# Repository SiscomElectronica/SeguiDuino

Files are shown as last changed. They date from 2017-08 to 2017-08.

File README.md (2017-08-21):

# SeguiDuino

Shield seguidor de lineas para el Arduino UNO

## Descripcion

El proyecto consta de 3 archivos importantes:

*SiscomSeguidor_1.sch: Diagrama electrico del proyecto

*SiscomSeguidor_1.brd: Archivo del diseño del circuito impreso

*SiscomSeguidor_Componentes.pdf: Archivo PDF de los componentes del circuito

*SiscomSeguidor_Pistas.pdf: Archivo PDF con el diseño de pistas

## Consideraciones

Muchos componentes fueron modificados desde su libreria, asi que puede 
marcar algunos errores con respecto a su descarga y posterior modifcacion.

Con respecto a su fabricacion al no tener archivos (.gbr) gerber es 
necesario contactar al fabricante y proporcionarle el archivo 
Siscom_SEGUIDOR.brd para su posterior manufacturacion.

Diseñado por: [Josue Echeverria](https://www.facebook.com/josue.echeverria.583)

Team SISCOM.

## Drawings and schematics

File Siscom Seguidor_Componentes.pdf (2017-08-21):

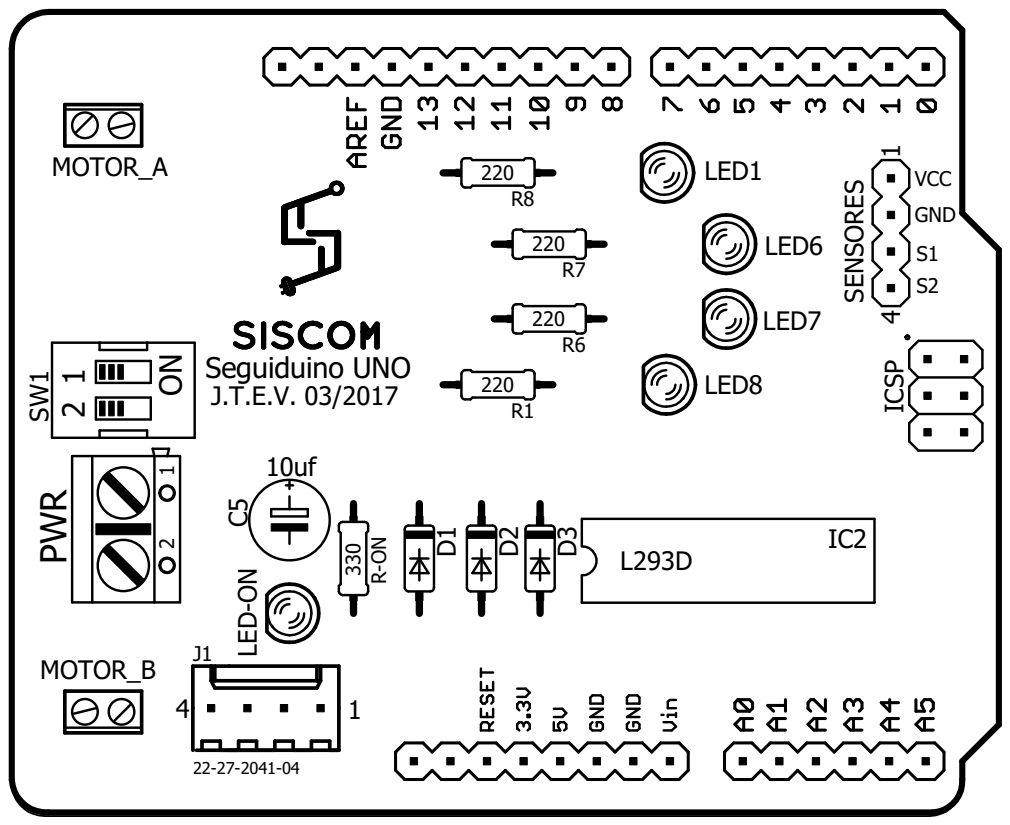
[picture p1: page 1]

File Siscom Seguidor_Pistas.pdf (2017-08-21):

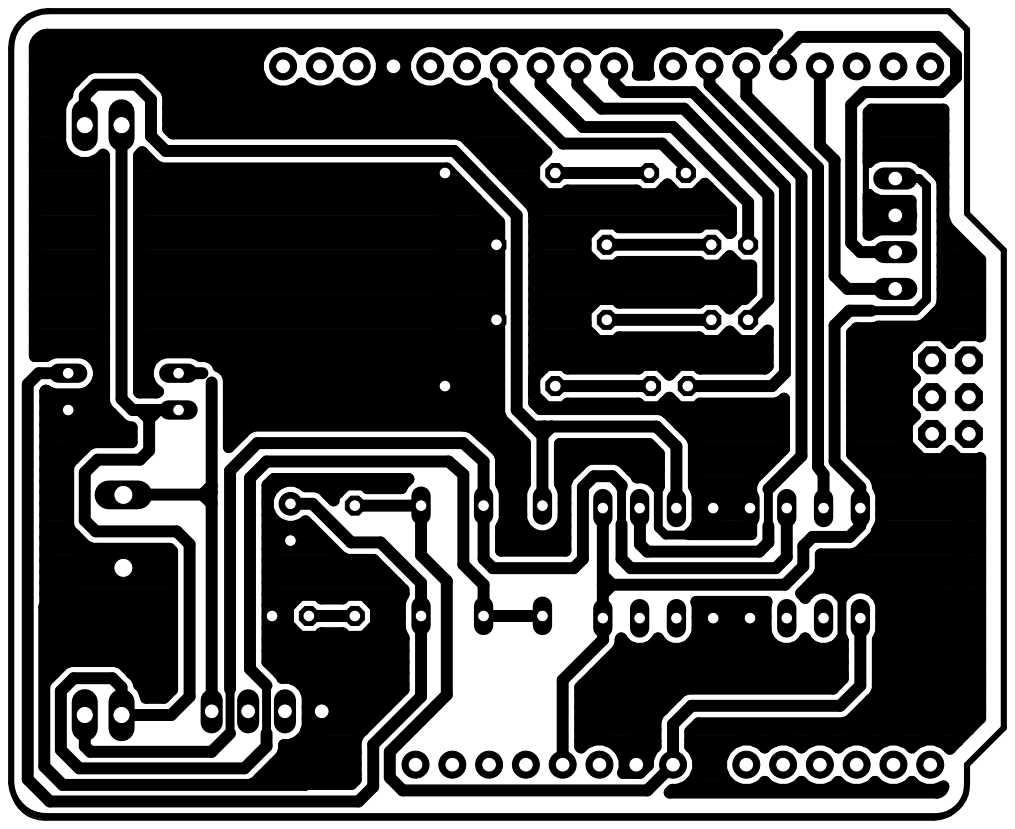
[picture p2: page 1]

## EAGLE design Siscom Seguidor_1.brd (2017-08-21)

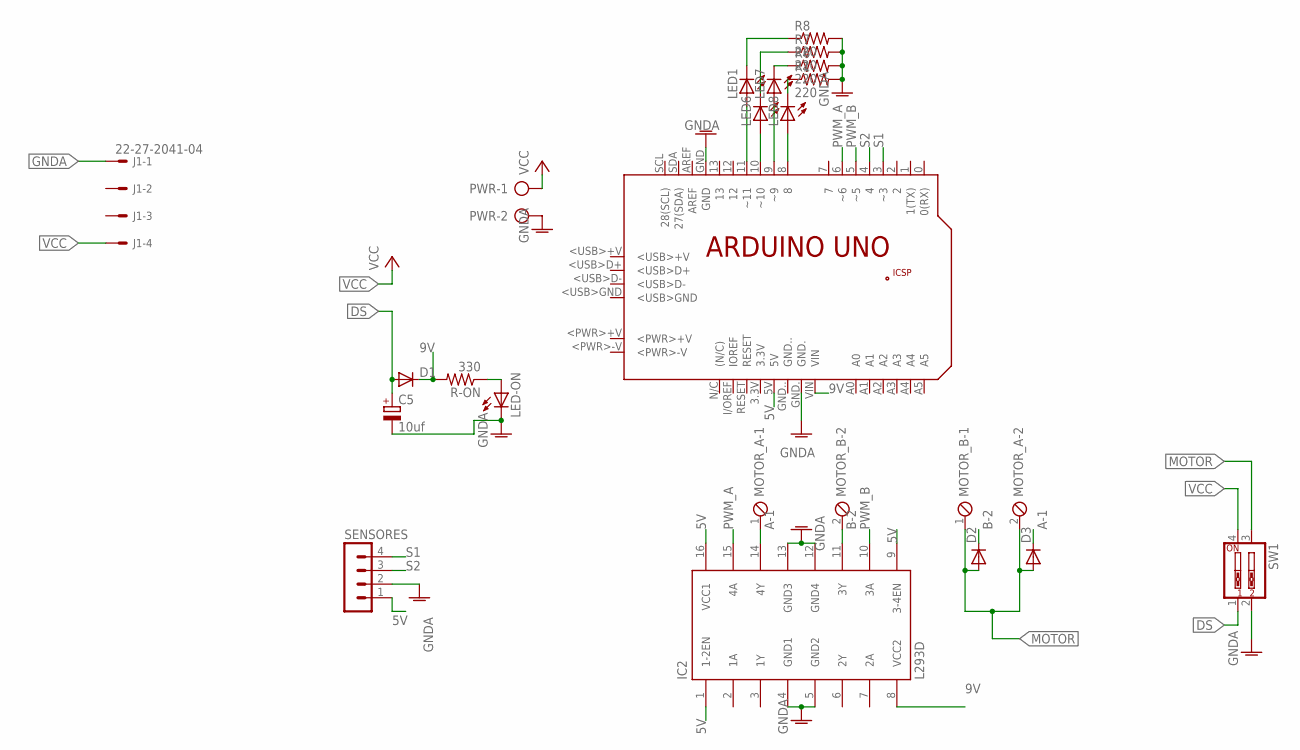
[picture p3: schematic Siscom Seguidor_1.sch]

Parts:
C5: 10uf; E2,5-6E
D1, D2, D3: 1N4148DO35-7; DO35-7
IC2: L293D; DIL16
J1: 22-27-2041-04; 6410-04
LED1, LED6, LED7, LED8: LED3MM
LED-ON: LED3MM
MOTOR_A: MPT2; 2POL254
MOTOR_B: MPT2; 2POL254
PCB2: ARDUINO_UNO
PWR: AK500/2
R1, R6, R7, R8: 220; 0204/7
R-ON: 330; 0204/7
SENSORES: MA04-1
SW1: SW_DIP-2; EDG-02

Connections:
5V: IC2.1 (1-2EN), IC2.9 (3-4EN), IC2.16 (VCC1), PCB2.5V, SENSORES.1
9V: D1.C, IC2.8 (VCC2), PCB2.VIN, R-ON.2
A-1: D3.C, IC2.14 (4Y), MOTOR_A.1
B-2: D2.C, IC2.11 (3Y), MOTOR_B.2
DS: C5.+, D1.A, SW1.1
GNDA: C5.-, IC2.4 (GND1), IC2.5 (GND2), IC2.12 (GND4), IC2.13 (GND3), J1.1, LED-ON.K (C), PCB2.GND, PCB2.GND., PWR.2, R1.2, R6.2, R7.2, R8.2, SENSORES.2, SW1.2
MOTOR: D2.A, D3.A, MOTOR_A.2, MOTOR_B.1, SW1.3
unnamed: LED-ON.A, R-ON.1
unnamed: LED8.K (C), R1.1
unnamed: LED7.K (C), R6.1
unnamed: LED6.K (C), R7.1
unnamed: LED1.K (C), R8.1
unnamed: LED7.A, PCB2.9 (~9)
unnamed: LED1.A, PCB2.11 (~11)
unnamed: LED6.A, PCB2.10 (~10)
unnamed: LED8.A, PCB2.8
PWM_A: IC2.15 (4A), PCB2.6 (~6)
PWM_B: IC2.10 (3A), PCB2.5 (~5)
S1: PCB2.3 (~3), SENSORES.4
S2: PCB2.4, SENSORES.3
VCC: J1.4, PWR.1, SW1.4

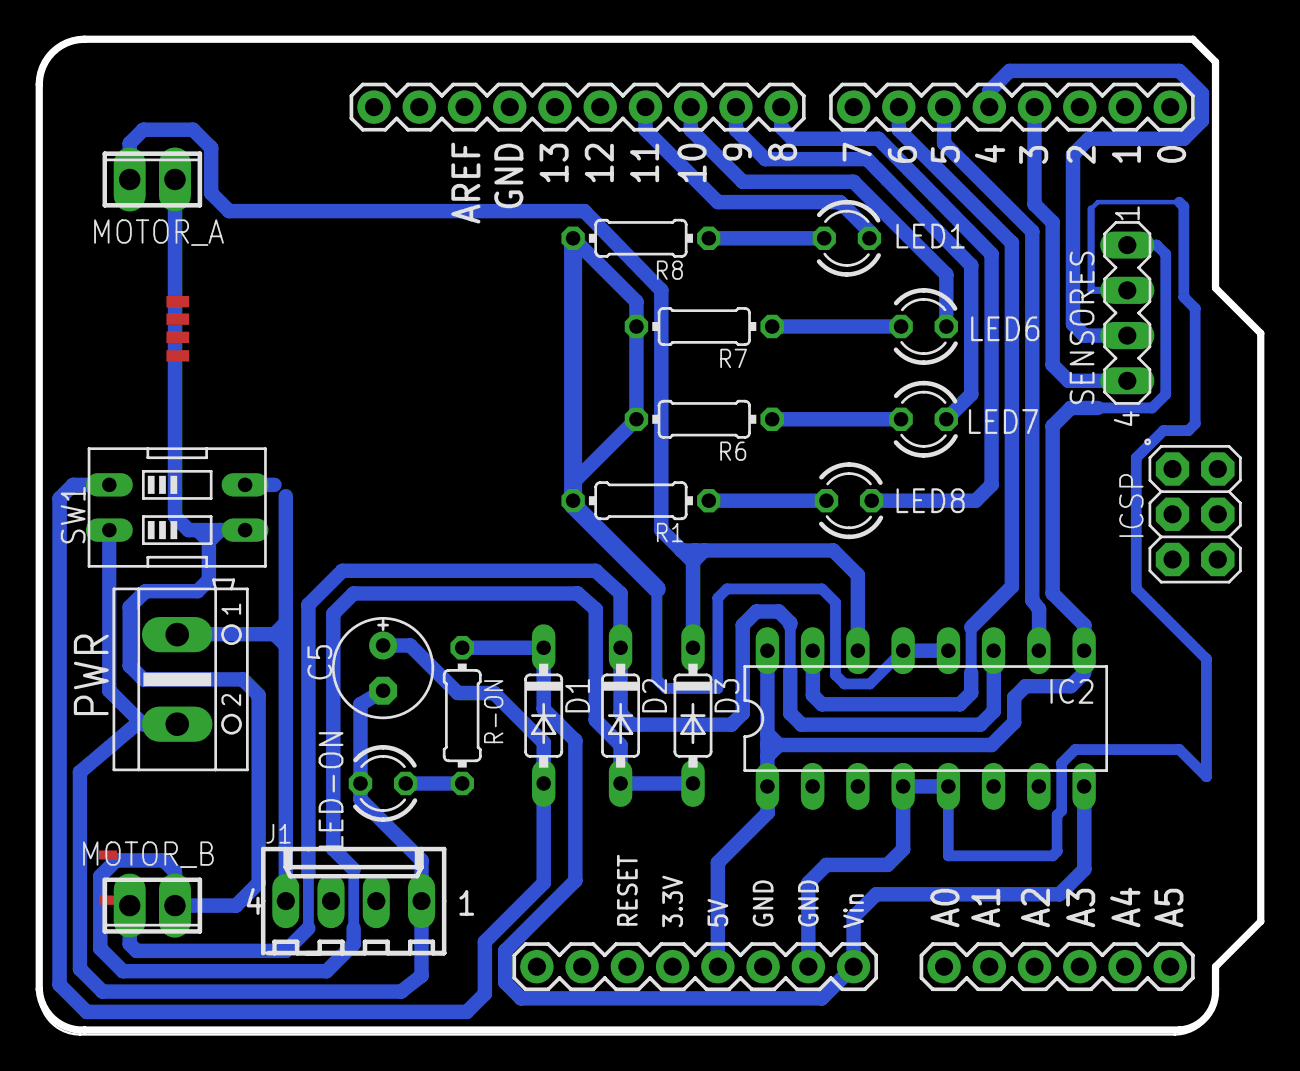
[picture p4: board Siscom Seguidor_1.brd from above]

Board: 2 copper layers, 68.6 x 55.9 mm, 22 parts (0 on the bottom side), 21 nets.
